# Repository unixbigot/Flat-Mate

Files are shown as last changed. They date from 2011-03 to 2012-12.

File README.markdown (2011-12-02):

Flat Mate - a battery voltage monitor with ATTiny45
===================================================

This project monitors the voltage of a battery and displays a
5-element bar-graph indicating battery charge state.  Optionally
MOSFET control may be used to cut off supply to protect the battery
from over-discharge.

See construction pictures on [my blog](http://blog.unixbigot.id.au/2011/03/flat-mate-protect-your-lipo-cells-from.html)

It is particularly applicable for multi-cell Lithium-ion Polymer
(LiPo) packs, which are easily ruined if over-discharged.

It is intended for use in high power applications such as portable
lighting, robotics and power tools where a charged SLA or LiPo battery
is discharged in the presence of a human operator.  The first
deployment was for a high-power bicycle headlamp.  Design was inspired
by the simple state-of-charge indicators present on some electric
bicycles.

The advantage over existing inexpensive "off the shelf" protection
circuits is that this circuit gives a visual indication of
state-of-charge, presented as an easy-to-read bar-graph.  Existing
protection circuits (often designed for flashlights or model aircraft)
either have no display (sudden surprise cutoff), digital voltage
display (requires memorizing cutoff voltages) or audio-only alert (no
visual display).

An Atmel ATTiny45 microcontroller is used to sample the battery
voltage and control the LED bargraph.  Power for the microcontroller
is derived from a 78L05 regulator connected to the main battery.
Battery voltage is monitored using an analog input via a voltage
divider and compared to the microcontroller's 1.1v internal voltage
reference.

The bargraph will show 4 LEDs when at "full charge" and 
1 LED when at minimum usable voltage.  When voltage is critical
a 5th "alert" LED will illuminate (and output supply can be terminated).

The circuit can be used purely as a voltage indicator by leaving off
the optional MOSFET switch components.  If a MOSFET is fitted this can
be used to disconnect the main load when the battery is depleted.

Hardware Details
----------------

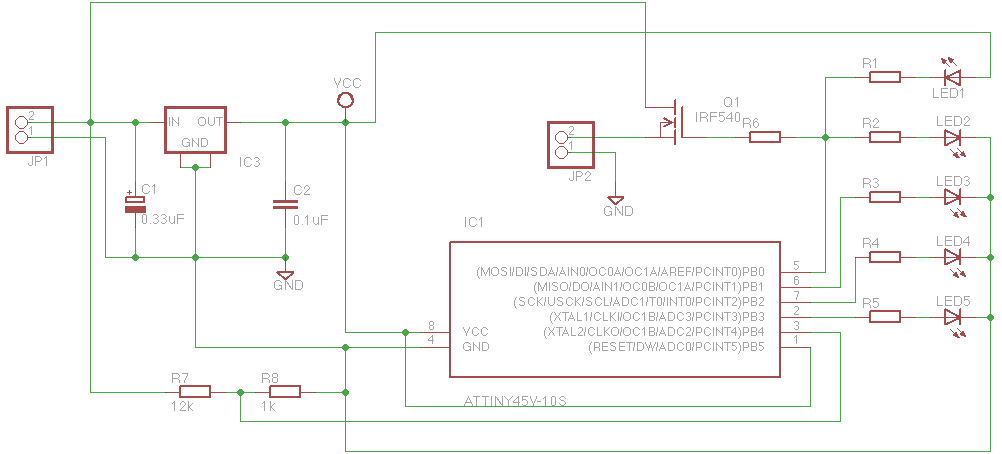
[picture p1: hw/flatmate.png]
schematic


The bargraph consists of 5 3mm LEDs (green, yellow and red) arranged
GYYYR.  The first four (GYYY) form the bargraph and the 5th (red) is
the critical alert.  The first three are connected to dedicated output
pins, the final two share a single pin in a totem-pole arrangement.
The fourth LED shares state with the output FET (if fitted), when this
LED is lit, power is good and the FET is enabled.  When this output
pin is cleared, the fifth LED (the complementary red CRITICAL
alert) is illuminated and the FET is disabled.

As the monitor circuit is indended for use in high-drain situations
(0.5--10A), the approx 20mA consumed by the monitoring circuit is
considered negligible.  In particular the voltage divider is not
isolated from supply between samples, so presents a constant drain of
around 850uA.  Current through the bargraph elements is limited by a
1kΩ resistor to around 3mA per element, so the bargraph consumes up to
12mA when at FULL level.

Software Details
----------------

Software is configurable for the type and number of cells.   The
initial application of a 3-cell (11.4v nominal) Lithium-ion Polymer
(LiPo) battery will be used to describe the code.

Four voltage thresholds are configured (in millivolts), depending on battery type.
For a 3S LiPo these are:

	    BMV_FULL = 12.000v
	    BMV_GOOD = 11.000v
	    BMV_LOW  = 10.000v
	    BMV_CRIT =  9.000v

The code converts these thresholds to analog sample values at compile
time, defining corresponding VL_FULL..CRIT constants.

These thresholds give the following LED readouts:

	    if >= FULL output GYYY_
	    if >= GOOD output _YYY_
	    if >= LOW  output __YY_
	    if >= CRIT output ___Y_
	    if  < CRIT output ____R

### Setup

   * Configure analog pin as input
   * Configure LED pins as outputs
   * Strobe the LEDs for 1s to see that they all work
   * Configure timer 1 to give 4Hz interrupts
   * Configure ADC for internal 1v1 reference, selecting single-ended channel 2 
   * Set ADC clock prescaler to give 125kHz, take and discard one sample

### Main loop

   * do nothing, go straight to sleep mode until timer interrupt.

### Timer interrupt handler

   * Read battery voltage
      * initiate conversion
      * busy-wait until conversion complete
      * read completed value
   * Update sample value
      * add sample value to accumulator
      * if 4 samples are accumulated, calculate the average and reset accumulator
   * Update the display whenver accumulator is reset
      * Clear all LEDs
      * Light the CRITICAL LED (and kill power) if level is <=VL_CRIT
      * Set the bargraph appropriately if level is >VL_CRIT (see above)

Since samples are accumulated at 4Hz, and each 4 samples are averaged,
the outputs will be changed only once per second.  Averaging is used
to avoid falsely detecting a CRITICAL state when transient spikes such
as motor start occur.

Construction
============

The circuit was prototyped on a solderless breadboard, with battery
simulated using a 24v supply and an adjustable-output regulator
(LM317T).

A selection of LEDs with one leg replaced by a current-limiting
resistor have been made to simplify use of LEDs in breadboard
prototypes.

For in-circuit programming I use the tuxgraphics AVRUSB500v2, as this
programmer features a 5-pin SIL programming header, which is very
convenient for breadboards.   

Once the design was proven, a version was constructed on through-hole
prototyping board with components arranged to take advantage of
pin-bridging where possible.  This turned out to be difficult since
the chosen double-sided prototype board featured a solder mask that
was *VERY* resistant to bridging (this would normally be a laudable
feature).  A plain copper single-sided protoboard would have actually
been a better choice.

The prototype has been deployed for use as a bicycle headlamp battery
pack.

Subsequent revisions will use ATTiny25 in SMD package, and SMD
components.

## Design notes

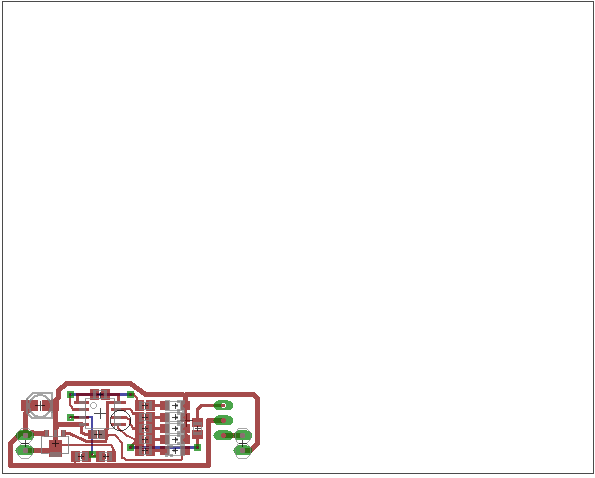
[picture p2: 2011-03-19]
hw/flatmate-long-brd.png

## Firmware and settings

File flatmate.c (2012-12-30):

/*
 * Flat Mate - Simple Li-poly battery monitor
 *
 * DEVICE: attiny45
 * FUSES:  LHX: 0x062 0xDF 0xFF -- 1MHz RC oscillator
 */

#include <inttypes.h>
#include <avr/io.h>
#include <avr/interrupt.h>
#include <avr/sleep.h>
#include <util/delay.h>

#include "avr_adc.h"

#if defined(__AVR_ATtiny45__) || defined(__AVR_ATtiny25__) 
/* 
 *@@ Pin assignments for ATtiny45
 * 
 * Pins:
 *
 * LEDA - (PB0) battery level ok led (yellow /red bicolour totem-pole arrangement)
 * LEDB - (PB1) battery level low led (yellow)
 * LEDC - (PB2) battery level good led (yellow)
 * LEDD - (PB3) battery level full led (green)
 * BATI - (PB4) Battery voltage sense input 
 *
 * Interrupts:
 *
 * TICK - timer tick from internal timer 1 (clk/2048) = 1MHz/2k + TOP=122 => 4.0023 Hz
 * ADC  - ADC conversion interrupt
 *
 */

#define TICK_OCR		OCR1C
#define TICK_TOP		122
#define TICK_CLK_DIV_1024	(_BV(CS13)|_BV(CS11)|_BV(CS10))
#define TICK_CLK_DIV_2048	(_BV(CS13)|_BV(CS12))
#define TICK_CLK_DIV_4096	(_BV(CS13)|_BV(CS12)|_BV(CS10))
#define TICK_CLK_DIV_16384	(_BV(CS13)|_BV(CS12)|_BV(CS11)|_BV(CS10))
#define TICK_CLK_MODE		TICK_CLK_DIV_2048
#define TICK_OVF_VECT		TIM1_OVF_vect

// Primary output is a "battery OK/Alert" signal on PB0 that drives
// a BiColor LED and/or a MOSFET.
//
// Secondary output is a three-element bargraph on PB[123]
//
#define LED_DDR			DDRB
#define LED_PORT		PORTB
#define LED_PIN			PINB
#define LEDA_BIT		PB0
#define LEDB_BIT		PB1
#define LEDC_BIT		PB2
#define LEDD_BIT		PB3

#define LEDA_BV			_BV(LEDA_BIT)
#define LEDB_BV			_BV(LEDB_BIT)
#define LEDC_BV			_BV(LEDC_BIT)
#define LEDD_BV			_BV(LEDD_BIT)
#define LEDALL_BV		(LEDA_BV|LEDB_BV|LEDC_BV|LEDD_BV)

// battery voltage level (Vb) input uses Analog input 2 on PB4 (pin 3)
// Vb/12 via voltage-divider is compared against internal 1.1V reference 
// (ADC unit has choice of 1.1v, 2.56v and 5v(VCC) references.)
#define BATI_DDR		DDRB
#define BATI_PORT		PORTB
#define BATI_BIT		PB4
#define BATI_BV			_BV(BATI_BIT)

#else
// insert constants for other supported chips here
#error unsupported chip
#endif

/* 
 *@ Configuration constants 
 *
 * 
 */
#define USE_TIMER 1
#define USE_BARGRAPH 1
#define CELL_COUNT 3

/* 
 *@@ Voltage trigger levels.
 *
 * Battery voltage is read through a voltage divider and compared to the internal voltage reference.
 *
 * If 
 *    Vin ----+
 *            R1
 *            +----- Vout (BATI)
 *            R2
 *            |
 *            =
 *            .  (gnd)
 *
 * Then Vout = Vin * ( R2 / (R1 + R2) ) 
 *
 * ; Use this Emacs lisp function to calculate divisors
 * (defun rn2div (rup rdown) (/ (float rdown) (+ rup rdown)))
 *
 * 
 * eg. R1=12k R2=1k => Vout = Vin * (1000 / (1000 + 12000))
 *                            Vin * 0.0769
 *
 *     R1=20k R2=10k => Vout = Vin * 0.3333   Ileak = 0.4mA @ 12v
 *     R1=2k2 R2=1k  => Vout = Vin * 0.3125
 *     R1=3k3 R2=1k  => Vout = Vin * 0.232
 *     R1=3k9 R2=1k  => Vout = Vin * 0.204    Ileak = 2.4mA @ 12v
 *     R1=39k R2=10k => Vout = Vin * 0.204    Ileak = 0.24mA @ 12v
 *     R1=4k7 R2=1k  => Vout = Vin * 0.175
 *     R1=10k R2=1k  => Vout = Vin * 0.0909   Ileak = 1mA @ 12v
 *     R1=12k R2=1k  => Vout = Vin * 0.0769   Ileak = 0.92mA @ 12v
 *
 * Fully charged LiPo is 4.23v/cell, discharged is 2.7v/cell (nominal voltage 3.7v/cell)
 * For battery endurance, do not discharge below 3.0v/cell (aircraft users commonly use 2.9v/cell as limit)
 *
 * A 2-cell battery (nominally 7.46v)  varies     from 8.46v to 5.40v, with low-volt alert at 6.00v
 * A 3-cell battery (nominally 11.1v) thus varies from 12.9v to 8.10v, with low-volt alert at 9.00v
 * A 4-cell battery (nominally 14.8v) thus varies from 16.9v to 10.8v, with low-volt alert 12 12.0v
 *   NOTE: a 4-cell battery requires a different voltage divider than 2-and-3 cells (use 15:1 not 12:1)
 *
 *
 *@@ Analog read values for defined voltage levels
 *
 * For a 3-cell battery, we consider 12v+ to be "full", 11v "good", 10v "low" and 9v "critical" 
 * (BMV_foo constants are these values in millivolts)
 *
 * In AVR-worldview, we use 12:1 voltage divider and read 10-bit ADC comparisons versus AREF (1.1v)
 *  
 * So 12v becomes 1.00V when divided.   
 * Compared to 1.1v reference this gives an ADC result of 1024*(1.0/1.1) == 859
 *
 * An alternative approach is to use a smaller voltage divisor and compare
 * against Vcc (5.0v), but in practice a 12:1 divisor is easier to achieve
 * due to the standard first preference resistor value series.
 *
 * You can use these Emacs lisp defuns to calculate threshold analog values for your voltage levels
 *
 * (defun volts2int (v sf ref) (round (/ (* 1024.0 (* (float v) sf) ) (float ref))))
 * (defun vlist2int (sf ref levels) (mapcar (lambda (v) (volts2int (float v) sf ref)) levels))
 * eg. (volts2int 12 0.333 5.0) => 818
 *     (vlist2int (rn2div 10000 1000) 1.1 '(12 11 10 9)) => (1016 931 846 762)
 *     (vlist2int (rn2div 20000 10000) 5.0 '(12 11 10 9)) => (819 751 683 614)
 *     (vlist2int (rn2div 12000 1000) 1.1 '(12 11 10 9))=> (859 788 716 644)
 *
 * for 4-cell, use a 15:1 divider
 *     (vlist2int (rn2div 15000 1000) 1.1 '(16 14.5 13 12)) => (931 844 756 698)
 *
 * The above lines calculate the VL_* values shown below
 */

#if CELL_COUNT == 4
/* Use a 15:1 voltage divider */

#define BMV_FULL 16000
#define VL_FULL    931

#define BMV_GOOD 14500
#define VL_GOOD    844

#define BMV_LOW  13000
#define VL_LOW     756

#define BMV_CRIT 12000
#define VL_CRIT    698

#elif CELL_COUNT == 3
/* Use a 12:1 voltage divider */

#define BMV_FULL 12000
#define VL_FULL    859

#define BMV_GOOD 11000
#define VL_GOOD    788

#define BMV_LOW  10000
#define VL_LOW     716

#define BMV_CRIT  9000
#define VL_CRIT    644

#elif CELL_COUNT == 2
/* Use a 12:1 voltage divider */

#define BMV_FULL  8000
#define VL_FULL    573

#define BMV_GOOD  7300
#define VL_GOOD    523

#define BMV_LOW   6650
#define VL_LOW     476

#define BMV_CRIT  6000
#define VL_CRIT    430

#else
#error "Unsupported cell count"
#endif


/* 
 *@ Global data
 * 
 * We take 4 samples (storing results in accumulator) then take an average.
 *
 */
#define SAMPLE_SIZE 4
char nsample;  /* current number of samples in accumulator */
int sum;       /* value of accumulator (sum of samples) */
int level;     /* voltage level (mean of previous sample set) */


void delay_1s(void)
{
	char i;
	for (i=0;i<100;i++)
		_delay_ms(10);
}


/* 
 *@ Application subroutines
 */
void update_leds(unsigned int level) 
{
	/* 
	 * Copy current port value into temporary storage for modification.
	 * This allows atomic update without turning off the load power.
	 */
	unsigned char leds = LED_PORT;

	leds &= ~LEDALL_BV;
	/*
	 * The critical level LED is independent of the bargraph leds.
	 * It's a biColor RED when crit, and YELLOW for power-on-voltage-OK
	 * The same pin may also be connected to a FET that can turn off the load
	 */
	if (level > VL_CRIT)
	{
		/* battery is OK, yellow LED lit, FET active */
		leds |= LEDA_BV;
	}
	/* otherwise battery is FLAT, red LED lit, FET off */

#if USE_BARGRAPH
	/* 
	 * OPTIONAL 3-element Bargraph showing state-of-charge. 
	 *
	 * >=FULL GYYY_
	 * >=GOOD _YYY_
	 * >=LOW  __YY_
	 * >=CRIT ___Y_
	 * <CRIT  ____R
	 *
	 */
	if (level >= VL_FULL)
	{
		/* battery FULL or higher */
		leds |= (LEDB_BV|LEDC_BV|LEDD_BV);
	}
	else if (level >= VL_GOOD) 
	{
		/* battery GOOD or better */
		leds |= (LEDB_BV|LEDC_BV);
	}
	else if (level >= VL_LOW) 
	{
		/* battery better than LOW */
		leds |= LEDB_BV;
	}
	/* 
	 * Between LOW and CRIT the bargraph will be dark, 
	 * only the BiColour CRIT/GOOD led will light (i.e. YELLOW=power good)
	 */
#endif

	/* Write back the modified port state */
	LED_PORT = leds;
}

void update_sample(int v) 
{
	/* 
	 * bump the global Count and Sum values, 
	 * and when we have accumulated SAMPLE_SIZE samples, compute an average
	 */
	sum += v;
	++nsample;

	if (nsample >= SAMPLE_SIZE) 
	{
		/* 
		 * we have a full set of samples, calculate mean and update display
		 */
		level = sum/nsample;
		update_leds(level);

		/* 
		 * reset accumulator
		 */
		nsample=0;
		sum=0;
	}
}

#if USE_TIMER
/* 
 *@ Interrupt Service routins
 *
 * At every clock interrupt we trigger an ADC input
 */
ISR(TICK_OVF_VECT)	
{
	/* 
	 * We got our 1/4 second interrupt
	 * 
	 * Read the analog input and update the sample set
	 */
	update_sample(adc_poll());
}

/* 
 * Interrupt service routine for Analog-to-Digital Conversion Complete
 *
 * We only ever use the one ADC channel (channel 2, PB4).
 */
ISR(ADC_vect)
{
	/* 
	 * An analog-to-digital conversion for pin BATI_BIT (PB0) has completed
	 */
	PINB|=LEDB_BV;
	ADCSRA|=_BV(ADIF);
	(void)adc_read();
}
#endif

/* 
 *@ IO init 
 */
void
ioinit (void)	
{
	int i,v;
	unsigned char l;
	
	/* 
	 * Set up BATI pin as analog input
	 */
	BATI_DDR &= ~BATI_BV;

	/* 
	 * Set up all LED pins as ouputs
	 *
	 * For debug, cycle a pattern across all leds for 1s
	 */
#if USE_BARGRAPH
	LED_DDR |= LEDALL_BV;
	LED_PORT &= LEDALL_BV;
	
	v=0;
	for (i=0; i<10; i++) {
		l = LED_PORT;
		l &= ~(LEDALL_BV);
		// Do not strobe the LEDA pin as this may control the load power
		switch(v)
		{
		case 0:
			l|=LEDB_BV;
			break;
		case 1:
			l|=LEDC_BV;
			break;
		case 2:
			l|=LEDD_BV;
			break;
			v=-1;
		}
		v++;
		if (v>2)
			v=0;
		LED_PORT = l;
		_delay_ms(100);
	}
	LED_PORT &= ~(LEDALL_BV);
#else
	LED_DDR |= LEDA_BV;
#endif

#if USE_TIMER
	/* 
	 * Set up timer 1 as clock tick source
	 *
	 * FIXME: really could disable timer interrupts altogether and 
	 * set ADC to trigger from timer compare match
	 */
	TCCR1 |= _BV(PWM1A);    /* clear timer on OCR1C match, generate overflow interrupt */
	TCCR1 |= TICK_CLK_MODE; /* prescaler divider 2048 */
	TICK_OCR = TICK_TOP;
	TIMSK |= _BV(TOIE1);    /* overflow interrupt enable */
#endif
 
	/* 
	 * Set up analog-to-digital converter 
	 *
	 * Internal 1v1 reference, using single-ended channel 2 (PB4, pin 3)
	 */
	adc_setref(ADC_VREF_INT_1V1);
	
	ADMUX|=_BV(MUX1); // ADC2(PB4)
	//adc_setch(2);

	/* 
	 * set ADC clock prescaler - we have 1MHz clock, we want 50-200kHz ADclk
	 */
	adc_setprescaler(ADC_PRESCALER_DIV8);

	/* 
	 * enable ADC unit by settting ADEN in ADCSRA
	 */
	adc_enable(1);

	/* 
	 * Perform one (polled) conversion and discard result
	 * (datasheet says first conversion after ADC enable is less accurate than subsequent)
	 */
	(void)adc_poll();

#if 0 && USE_TIMER
	/* 
	 * enable ADC interrupts
	 */
	ADCSRA|=_BV(ADIF);
	ADCSRA&=~_BV(ADATE);
	ADCSRA |= _BV(ADIE);
	//adc_intenable(1);
#endif
	
	sei ();
}

int
main (void)
{
	
	ioinit ();
	
	/* loop forever, the interrupts are doing the rest */
	for (;;) 
	{
#if USE_TIMER		
		sleep_mode();
#else
		/* 
		 * take an analog sample, save sample, update leds
		 */
		update_sample(adc_poll());
		_delay_ms(250);
#endif		
	}
	
	return (0);
}

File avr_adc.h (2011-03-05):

#ifndef _AVR_ADC_H
#define _AVR_ADC_H

/* 
 *@ ADC control constants
 * 
 */
#define ADC_VREF_VCC 0
#define ADC_VREF_EXT_PB0 _BV(REFS0)
#define ADC_VREF_INT_1V1 _BV(REFS1)
#define ADC_VREF_INT_2V56 (_BV(REFS2)|_BV(REFS1))
#define ADC_VREF_INT_2V56_BYPASS (_BV(REFS2)|_BV(REFS1)|_BV(REFS0))

#define ADC_PRESCALER_DIV2 _BV(ADPS0)
#define ADC_PRESCALER_DIV4 _BV(ADPS1)
#define ADC_PRESCALER_DIV8 (_BV(ADPS1)|_BV(ADPS0))
#define ADC_PRESCALER_DIV16 _BV(ADPS2)
#define ADC_PRESCALER_DIV64 (_BV(ADPS2)|_BV(ADPS1))
#define ADC_PRESCALER_DIV128 (_BV(ADPS2)|_BV(ADPS1)|_BV(ADPS0))

/* 
 *@ ADC control function prototypes 
 *
 * A real simple abstraction for the Analog-to-Digital converter
 *
 * These simple functions (many of them 1-liners) may work out _fatter_ than just 
 * inlining the bit-twiddlery, but in cases where you have the room to spare, 
 * the code is much more maintainable.
 *
 */
extern void adc_enable(unsigned char on);
extern void adc_setref(unsigned char ref);
extern void adc_setch(unsigned char ch);
extern void adc_setprescaler(unsigned char ps);
extern void adc_intenable(unsigned char on);

extern void adc_start(void);
extern int adc_wait(void);
extern int adc_read(void);
extern int adc_poll(void);


#endif

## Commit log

2011-03-03 Remove dead code, add 2-cell lipo case
2011-03-04 Import schematic (eagle cad format)
    [flatmate.sch]
2011-03-05 Lay out SMD board w/ throughole FET
    [flatmate.brd, flatmate.sch]
2011-03-15 Redo PCB
    [flatmate-long.brd, flatmate-long.sch]
2011-03-19 Don't bounce power during powerup animation
2011-03-19 Cleanup trace widths
    [flatmate-long.brd]
2011-03-19 Immages for schematic and board
2012-12-30 Board tweaks
    [flatmate-long.brd]
2012-12-30 Add support for 4-cell battery
